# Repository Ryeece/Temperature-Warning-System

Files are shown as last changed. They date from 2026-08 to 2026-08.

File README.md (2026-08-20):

# Temperature-Warning-System

Embedded temperature monitoring and warning system using an Arduino Mega 2560, DHT11, 16×2 LCD, and custom KiCad shield PCB

## Overview

Using the Arduino Mega I measured the temperature with a DHT11 sensor and had the live temperature reading displayed on the 16×2 LCD. When the set temperature threshold was exceeded a warning LED turns on with a warning message on the 16×2 LCD. For sensor faults the warning LED turns on with a check sensor message on the 16×2 LCD. Finally a custom Mega shield PCB was designed in KiCad.

## Features

- Live temperature measurement
- Temperature threshold warning
- Sensor fault detection
- LCD status messages
- Standalone battery operation
- Custom PCB shield

## Hardware Used

- ELEGOO Arduino Mega 2560
- DHT11 temperature and humidity module
- 1602A V2.0 16×2 LCD
- 10 kΩ potentiometer
- LED
- 220 Ω resistor
- Breadboard
- Jumper wires
- Battery power supply
- Custom Arduino Mega shield PCB designed in KiCad to replace the breadboard and jumper wires

## System Operation

First the DHT11 takes the temperature reading, then it sends the data to the Mega and the Mega processes the reading using the uploaded code and displays the temperature on the LCD. If the temperature threshold is exceeded the warning LED turns on and a warning message is displayed on the LCD. Finally the function `isnan()` is used to detect an invalid sensor reading which activates the warning LED and error message on the LCD.

## Breadboard Prototype
The system was first built and tested on a breadboard before being transferred into the custom Arduino Mega shield PCB design.

The temperature threshold was temporarily set to 29.8°C so the high-temperature warning could be tested at room temperature.

- Normal operation — LCD shows live temperature and Normal temp, LED off:

Normal operation

- High-temperature warning — LCD shows TEMP TOO HIGH, warning LED on:

High-temperature warning

- Sensor fault — LCD shows the sensor error message, warning LED on:

Sensor fault

## Testing and Fault Handling

| Test | Expected Result | Result |
|---|---|---|
| Temperature below threshold | LED off and normal-temperature message displayed on the LCD | Pass |
| Temperature above threshold | LED on and high-temperature warning message displayed on the LCD | Pass |
| DHT11 signal disconnected | Warning LED on and sensor error message displayed on the LCD | Pass |
| Battery-powered operation | System operates without the laptop connection | Pass |

To test the `isnan()` fault handling, I deliberately disconnected the DHT11 signal.

## PCB Design

The PCB was designed as an Arduino Mega shield so it could plug directly into the Mega.

- A 16-pin header was added for the 16×2 LCD and a 3-pin header for the DHT11
- The LED, 220 Ω resistor and 10 kΩ potentiometer were placed on the shield
- The breadboard prototype was used to help plan the PCB layout
- ERC and DRC were used to check the design
- The final layout was checked in KiCad's 3D Viewer

KiCad schematic:

KiCad schematic

KiCad PCB layout:

KiCad PCB layout

3D view of the PCB Mega shield:

3D view of the PCB Mega shield

The Mega-template header footprints mainly establish the correct physical positions. In place of the female headers, male headers will be soldered underneath the physical PCB to allow connection to the Mega 2560, and female headers will be soldered on top for removable connections for the DHT11 and LCD.

## Problems Encountered and Fixes

| Problem | Cause | Fix |
|---|---|---|
| External LED did not light | Both LED legs were connected to the same breadboard node | Repositioned the LED so each leg was connected to a different node |
| LCD displayed dark blocks instead of text | D7 was connected incorrectly | Corrected the LCD wiring so D7 connected to the correct LCD pin |
| Invalid DHT11 reading | Sensor communication failed when the signal was disconnected | Added `isnan()` fault detection, an LCD error message and warning LED activation |
| KiCad ERC/DRC warnings | Unused and duplicated connections in the Arduino Mega template | Used No Connect flags, `PWR_FLAG`s and intentional exclusions where appropriate |

## Final Result

The DHT11 live temperature measurement was displayed on the LCD with a warning LED and high-temperature message when the temperature threshold was exceeded. The sensor fault detection worked by activating the warning LED and displaying an error message on the LCD. The system operated independently using battery power. The custom Mega shield PCB design was completed and checked with ERC and DRC, but the physical PCB manufacturing/soldering is still pending.

## Project Files

- [Arduino Code](code/Temperature%20Warning%20System.ino)
- [KiCad PCB Files](pcb/)
- [Project Report](documentation/Temperature%20Warning%20system%20report.pdf)

## Future Improvements

A temperature-controlled fan could be added that uses PWM (Pulse Width Modulation) based on the temperature, allowing the cooling rate to increase or decrease when needed.

To ensure the system never needs a temperature threshold code change again, some user-adjustable buttons to alter the threshold could be added.

The manufacturing and soldering of the custom PCB need to be completed.

Eventually, the Arduino Mega can be replaced with a microcontroller mounted directly on the PCB.

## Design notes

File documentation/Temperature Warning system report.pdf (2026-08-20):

# Temperature-Monitoring/Warning System

## By Ryeece Ashruff

19th August 2026

## Project aim and requirements

## Project Aim

This project aimed to create an embedded temperature-monitoring/warning system with the use of an Arduino Mega 2560. The system must have a constant reading of the ambient temperature using the DHT11 sensor and a constant display of the temperature on a 16x2 LCD. When the temperature exceeds the assigned threshold, a warning LED is activated along with a warning message on the LCD. The system should also be able to detect a failed sensor reading, triggering a fault condition. The final stage would be designing a custom Arduino Mega shield PCB to replace the breadboard's messy wiring.

## Requirements

- The system measures the temperature using a DHT11 sensor
- The measured temperature is displayed on a 16x2 LCD
- The system must compare the measured temperature to the warning threshold
- When the temperature is at or above the threshold, the warning LED must turn on
- When the temperature is at or above the threshold, the LCD must display a high temperature warning message
- Under normal temperature conditions, the LED will be off, and the LCD will read “normal temperature”
- An invalid DHT11 sensor reading should be detected, a sensor fault message displayed, and the LED activated
- The system must operate independently after programming with a battery power source
- A custom PCB should be designed for an Arduino Mega shield to replace the breadboard wiring.

## Hardware used

- ELEGOO Arduino Mega 2560
- DHT11temperature and humidity module
- 1602A V2.0 16x2 LCD
- 10 kΩ potentiometer
- LED
- 220Ω resistor
- Breadboard
- Jumper wires
- Battery
- Custom Arduino Mega shield PCB designed in KiCad

## Breadboard prototype

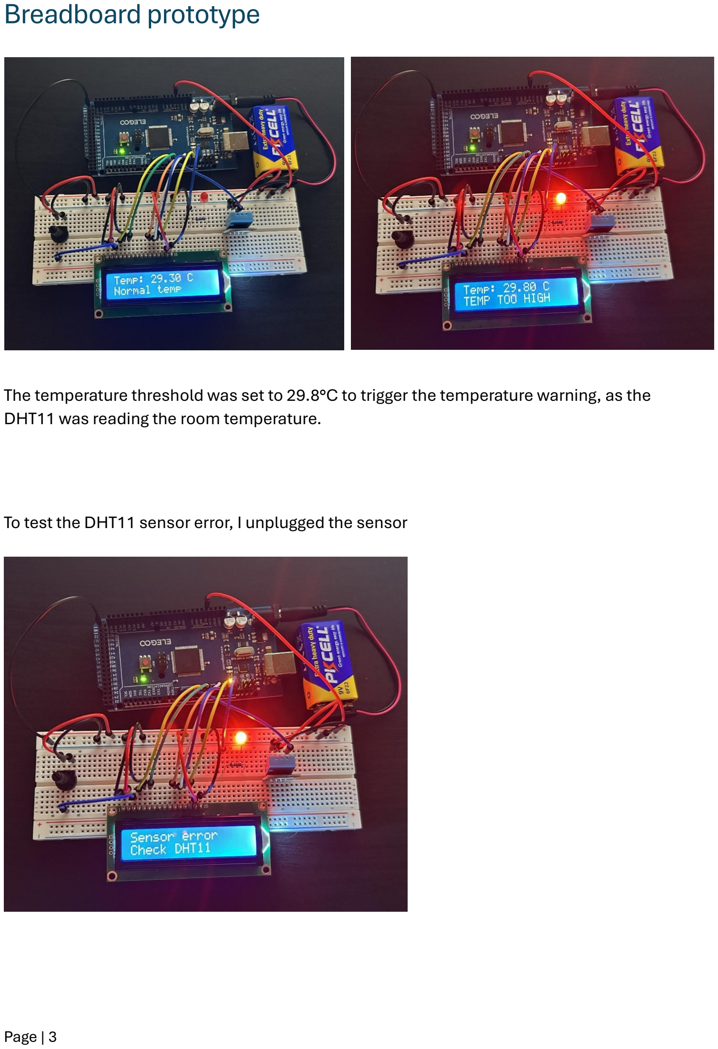
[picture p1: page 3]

The temperature threshold was set to 29.8°C to trigger the temperature warning, as the DHT11 was reading the room temperature.

To test the DHT11 sensor error, I unplugged the sensor

## Software/control logic

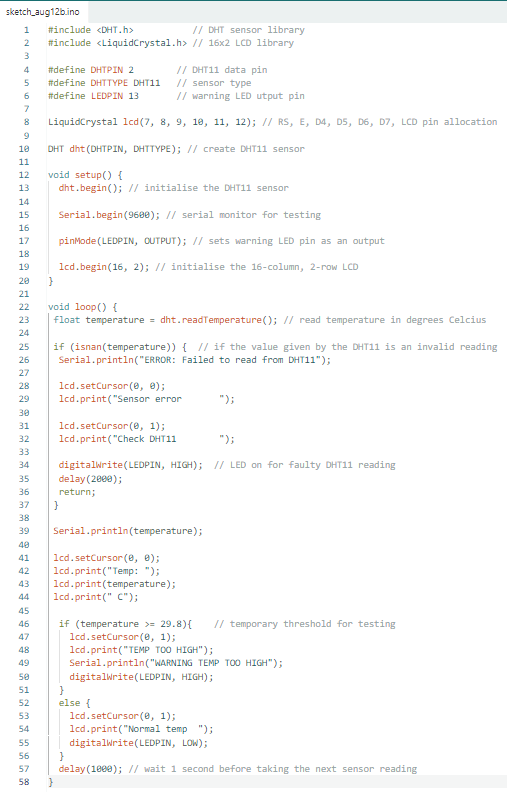
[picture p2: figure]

## Testing

Test | Expected result | Result
Temperature below threshold | LED off and LCD says normal temperature | Pass
Temperature above threshold | LED on and warning message on LCD | Pass
Sensor disconnected | Error message on LCD and LED on | pass
Battery powered | System runs independently | pass

The DHT11 sensor was checked using isnan(temperature) to identify a failed reading. If the reading was invalid, the LED turns on, and the LCD displays a sensor error message. To simulate a sensor fault, I temporarily disconnected the DHT11 signal connection.

## Problems encountered

Problem | Cause | Fix
LED not lighting up | Both LED legs were accidentally placed on the same breadboard path | Moved the legs to separate rows
LCD not displaying properly | D7 was incorrectly connected to backlight pin A | Moved the wire for D7 to the correct data pin
A failed DHT11 reading would leave the system reading invalid data | A broken or improper connection of the data pin or the power supply | Adding isnan(temperature) to check if the data is valid or not, resulting in an error message displayed and the warning LED on
PCB ERC/DRC issues | The unused Arduino Mega template pins and SDA/SCL connections created warnings/errors | Used no connect flags where appropriate; added PWR_FLAG for supply to +5V/GND, and excluded understood template-caused violations

## PCB design

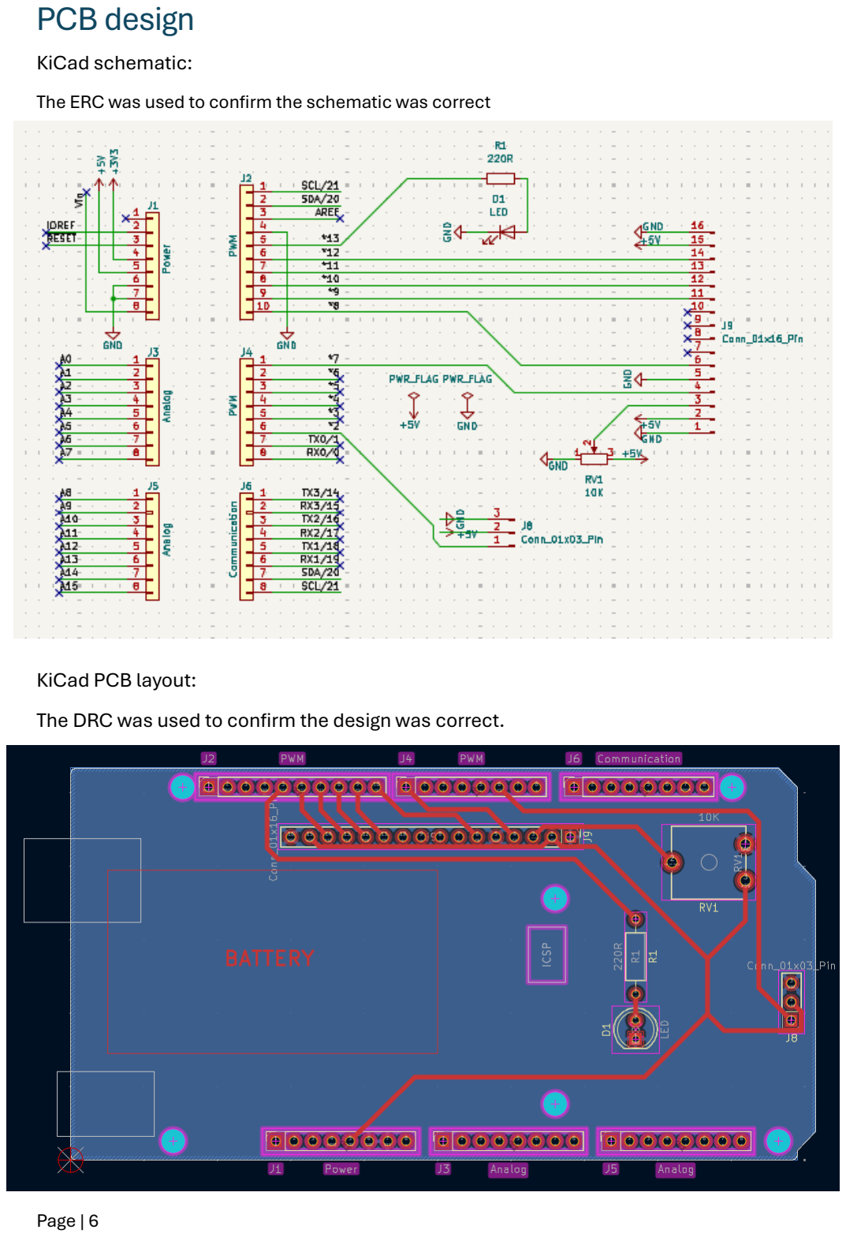
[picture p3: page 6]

KiCad schematic:

The ERC was used to confirm the schematic was correct

KiCad PCB layout:
The DRC was used to confirm the design was correct.

3D view of the PCB shield:

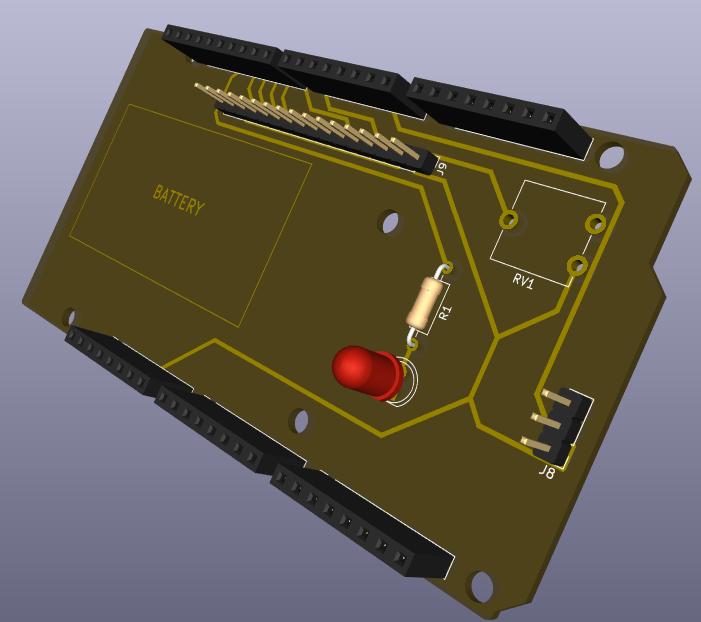
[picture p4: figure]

I designed the PCB as an Arduino Mega shield so it can plug directly onto the Mega 2560. All female headers will be replaced with male headers on the bottom of the PCB to allow it to plug into the Mega 2560. And the male headers on top will be changed to female headers, so the 16x2 LCD and DHT11 can be connected and remain removable.
The footprints assigned for the PCB design can be changed as needed when soldering on the headers. All that is required is the correct spacing and connections.
I measured my components in real life to choose the correct footprints needed.

## Final result

The temperature was successfully measured using the DHT11 and displayed on the 16x2 LCD. The warning LED worked for both high temperature and the sensor fault; the fault-detection logic for the sensor also worked as required, with the LCD displaying a warning/error message. The final breadboard design could operate independently from the laptop with a battery once programmed; finally, the breadboard prototype was made into a custom Arduino Mega shield PCB design.
The final physical stage is to manufacture and solder the custom PCB. This will be completed when soldering equipment is available at my university.

## Possible future improvements

A temperature-controlled fan could be added that uses PWM (Pulse Width Modulation) based on the temperature, allowing the cooling rate to increase or decrease when needed.
To ensure the system never needs a temperature threshold code change again, some user-adjustable buttons to alter the threshold could be added.
The manufacturing and soldering of the custom PCB need to be completed. Eventually, the Arduino Mega can be replaced with a microcontroller mounted directly on the PCB.

## References

Arduino (n.d.) Mega 2560 Rev3. Available at: https://docs.arduino.cc/hardware/mega-2560/ (Accessed: 17 August 2026).
Arduino (n.d.) Liquid Crystal Displays (LCD) with Arduino. Available at: https://docs.arduino.cc/learn/electronics/lcd-displays (Accessed: 17 August 2026). Adafruit Industries (n.d.) DHT sensor library. Available at: https://github.com/adafruit/DHT-sensor-library (Accessed: 17 August 2026).
KiCad Developers Team (2025) Getting Started in KiCad 9.0. Available at: https://docs.kicad.org/9.0/en/getting_started_in_kicad/getting_started_in_kicad.html (Accessed: 17 August 2026).
KiCad Developers Team (n.d.) PCB Editor 9.0. Available at: https://docs.kicad.org/9.0/en/pcbnew/pcbnew.html (Accessed: 17 August 2026). Aosong Electronics Co., Ltd. (n.d.) DHT11 digital humidity and temperature sensor datasheet. Available online (Accessed: 18 August 2026).
Used the datasheet for the 4-pin DHT11 sensor, as only the characteristics of the sensor itself were used, the project used a separate 3-pin breakout module containing the DHT11 sensor.

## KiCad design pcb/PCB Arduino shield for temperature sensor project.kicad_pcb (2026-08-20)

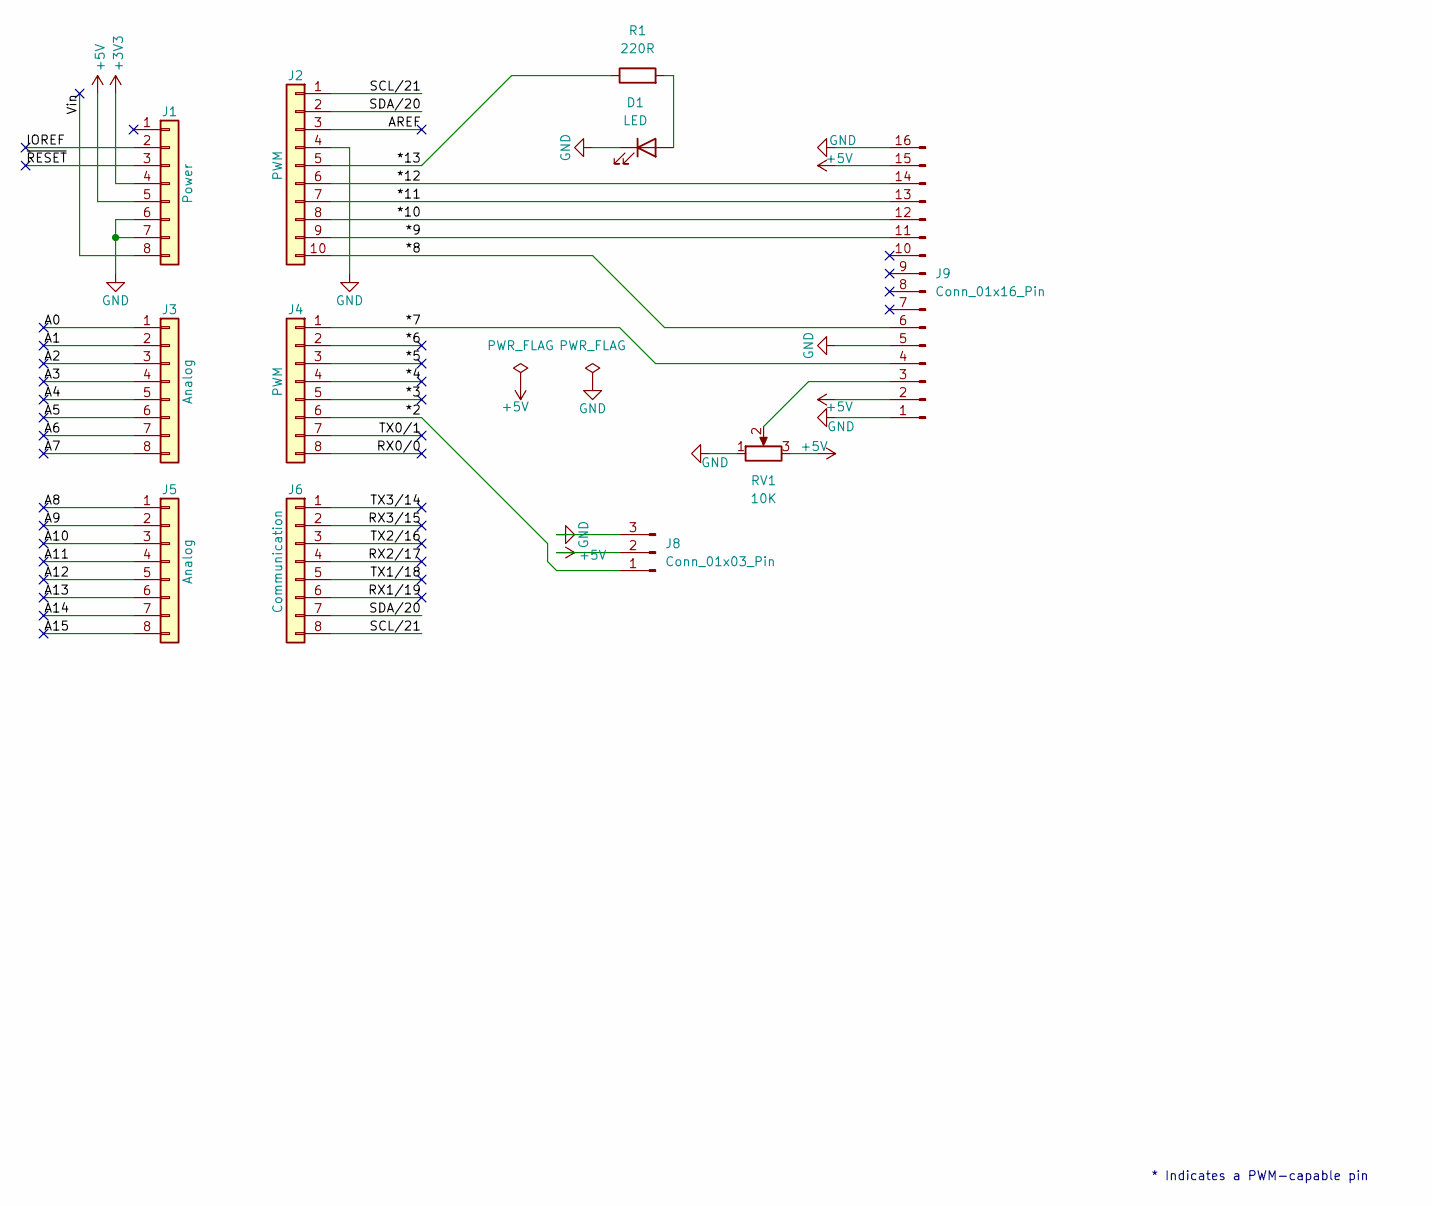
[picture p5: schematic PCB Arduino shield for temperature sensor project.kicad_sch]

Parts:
D1: LED; LED_D5.0mm
J1: Power; PinSocket_1x08_P2.54mm_Vertical
J2: PWM; PinSocket_1x10_P2.54mm_Vertical
J3, J5: Analog; PinSocket_1x08_P2.54mm_Vertical
J4: PWM; PinSocket_1x08_P2.54mm_Vertical
J6: Communication; PinSocket_1x08_P2.54mm_Vertical
J8: Conn_01x03_Pin; PinHeader_1x03_P2.54mm_Vertical
J9: Conn_01x16_Pin; PinHeader_1x16_P2.54mm_Vertical
R1: 220R; R_Axial_DIN0207_L6.3mm_D2.5mm_P10.16mm_Horizontal
RV1: 10K; Potentiometer_ACP_CA9-V10_Vertical

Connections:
+3V3: J1.4
+5V: J1.5, J8.2, J9.2, J9.15, RV1.3
/*2: J4.6, J8.1
/*3: J4.5
/*4: J4.4
/*5: J4.3
/*6: J4.2
/*7: J4.1, J9.4
/*8: J2.10, J9.6
/*9: J2.9, J9.11
/*10: J2.8, J9.12
/*11: J2.7, J9.13
/*12: J2.6, J9.14
/*13: J2.5, R1.1
/A0: J3.1
/A1: J3.2
/A2: J3.3
/A3: J3.4
/A4: J3.5
/A5: J3.6
/A6: J3.7
/A7: J3.8
/A8: J5.1
/A9: J5.2
/A10: J5.3
/A11: J5.4
/A12: J5.5
/A13: J5.6
/A14: J5.7
/A15: J5.8
/AREF: J2.3
/IOREF: J1.2
/RX0/0: J4.8
/RX1/19: J6.6
/RX2/17: J6.4
/RX3/15: J6.2
/SCL/21: J2.1, J6.8
/SDA/20: J2.2, J6.7
/TX0/1: J4.7
/TX1/18: J6.5
/TX2/16: J6.3
/TX3/14: J6.1
/Vin: J1.8
/~RESET: J1.3
GND: D1.1 (K), J1.6, J1.7, J2.4, J8.3, J9.1, J9.5, J9.16, RV1.1
unnamed: D1.2 (A), R1.2
unnamed: J9.3, RV1.2

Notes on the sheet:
* Indicates a PWM-capable pin

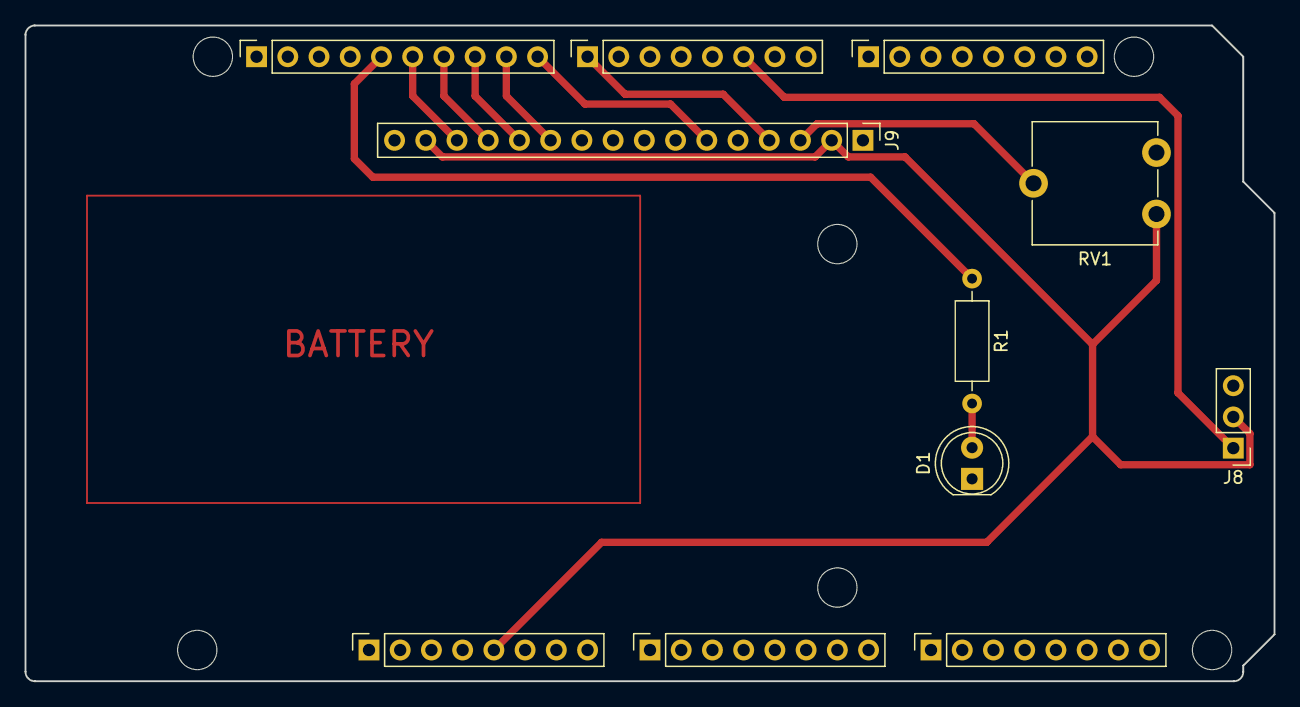
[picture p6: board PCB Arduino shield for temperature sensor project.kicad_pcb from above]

Board: 2 copper layers, 101.6 x 53.3 mm, 17 parts (0 on the bottom side), 14 nets.

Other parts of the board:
MH1, MH2, MH3, MH4, MH5, MH6: MountingHole_3.2mm

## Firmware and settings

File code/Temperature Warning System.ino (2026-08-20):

#include <DHT.h>           // DHT sensor library
#include <LiquidCrystal.h> // 16x2 LCD library

#define DHTPIN 2        // DHT11 data pin
#define DHTTYPE DHT11   // sensor type
#define LEDPIN 13       // warning LED utput pin

LiquidCrystal lcd(7, 8, 9, 10, 11, 12); // RS, E, D4, D5, D6, D7, LCD pin allocation

DHT dht(DHTPIN, DHTTYPE); // create DHT11 sensor 

void setup() {
  dht.begin(); // initialise the DHT11 sensor

  Serial.begin(9600); // serial monitor for testing

  pinMode(LEDPIN, OUTPUT); // sets warning LED pin as an output

  lcd.begin(16, 2); // initialise the 16-column, 2-row LCD
}

void loop() {
 float temperature = dht.readTemperature(); // read temperature in degrees Celcius

 if (isnan(temperature)) {  // if the value given by the DHT11 is an invalid reading
  Serial.println("ERROR: Failed to read from DHT11");

  lcd.setCursor(0, 0);
  lcd.print("Sensor error       ");

  lcd.setCursor(0, 1);
  lcd.print("Check DHT11        ");

  digitalWrite(LEDPIN, HIGH);  // LED on for faulty DHT11 reading
  delay(2000);
  return;
 }

 Serial.println(temperature);

 lcd.setCursor(0, 0);
 lcd.print("Temp: ");
 lcd.print(temperature);
 lcd.print(" C");

  if (temperature >= 29.8){    // temporary threshold for testing
    lcd.setCursor(0, 1);
    lcd.print("TEMP TOO HIGH");
    Serial.println("WARNING TEMP TOO HIGH");
    digitalWrite(LEDPIN, HIGH);
  }
  else {
    lcd.setCursor(0, 1);
    lcd.print("Normal temp  ");
    digitalWrite(LEDPIN, LOW);
  }
  delay(1000); // wait 1 second before taking the next sensor reading
}

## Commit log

2026-08-19 Expand README with additional sections
    Added sections for overview, features, hardware, operation, testing, PCB design, problems, final result, and future improvements.
2026-08-19 Fix Arduino model number and LCD character in README
    Corrected the model number of the Arduino and updated the LCD character representation.
2026-08-19 Update README with new features and hardware details
    Added features related to battery operation and custom PCB shield.
2026-08-19 Enhance README with system operation details
    Added explanation of system operation and sensor handling.
2026-08-19 Refine testing section in README.md
    Updated temperature message formatting and clarified battery operation description.
2026-08-19 Add PCB design image to README
    Added PCB design image to the README.
2026-08-19 Add additional PCB design images to README
2026-08-19 Add 3D view image of PCB Mega shield
    Added a 3D view image of the PCB Mega shield to the README.
2026-08-19 Fix formatting and enhance PCB design section
    Corrected formatting and added details about the PCB design process.
2026-08-19 Add images for KiCad schematic and PCB layout
2026-08-19 Correct capitalization in README for KiCad's 3D Viewer
2026-08-20 Update pin header description in README
    Clarified pin header information in README.
2026-08-20 Update README with clearer pin header explanation
    Clarified the explanation about pin headers and their replacements for the PCB.
2026-08-20 Update header footprint description in README
    Clarified the explanation of header footprints and their replacements for the PCB.
2026-08-20 Update README with final results and future improvements
    Added details about the final result and future improvements for the project, including temperature measurement, warning LED functionality, and potential enhancements.
2026-08-20 Enhance README with breadboard prototype details
    Added a section about the breadboard prototype and included an image demonstrating normal operation. Updated the Testing and Fault Handling section for clarity.
2026-08-20 Enhance README with operational details and images
    Updated the README to include additional details on normal operation, high-temperature warnings, and sensor faults with corresponding images.
2026-08-20 Update README with temperature threshold details
    Added temperature threshold information for warnings.
2026-08-20 Enhance README with project details and improvements
    Expanded README with detailed project overview, features, hardware used, system operation, testing, PCB design, problems encountered, and future improvements.
2026-08-20 Add Temperature Warning System sketch
2026-10-27 Document PCB manufacturing and assembly process
    Added a section on PCB manufacturing and assembly, detailing the process from design to testing. Updated the final result summary to reflect successful operation and skills developed during the proje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
2026-10-27 Enhance README with testing details and improvements
    Updated testing and fault handling sections with additional details on PCB testing and future improvements.
2026-10-27 Create Gerber-Files
2026-10-27 Add PCB manufacturing Gerber files
2026-10-27 Add link to PCB Manufacturing Files in README
2026-10-27 Fix link to PCB Manufacturing Files in README
